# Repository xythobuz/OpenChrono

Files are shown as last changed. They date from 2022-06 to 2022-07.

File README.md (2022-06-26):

# OpenChrono

Chronograph for Airsoft use, released as Free Open Source hardware and software!

Uses a 3D printed housing to hold an Arduino, an OLED display, batteries and two photosensitive IR light barriers.

Fixed mounting on the front of the gun in the style of a silencer.

Can optionally also include UV LEDs to illuminate tracer BBs.

Please also [take a look at the write-up on my website](https://www.xythobuz.de/openchrono.html)!

## Hardware

Use the included OpenSCAD design file in `hardware/openchrono.scad` to render your own custom STLs that fit your use-case.

### Required Parts

Besides some common stuff like soldering wire and hotglue you need the following parts to build this project.

| Description | Type | Count |
| --- | --- | ----- |
| Arduino Nano | | 1x |
| LCD 128x64 I2C | SSD1306 0.96" | 1x |
| Slide Switch | | 1x |
| IR Phototransistor | SFH 309 FA-5  | 2x |
| IR LED 3mm | | 2x |
| Resistor | 1k Ohm | 2x |
| Resistor | 50 Ohm | 1x |
| Screw | M2 10mm | 4x |
| Screw | M2.5 10mm | 2x |
| Screw | M3 16mm | 8x |
| Heatmelt Insert | M3 <= 10mm | 8x |

For the UV tracer option you also need the following parts.

| Description | Type | Count |
| --- | --- | ----- |
| UV LED 3mm  | | 2x |
| Resistor | 50 Ohm  | 1x |

You have different options for powering the project.
My first version for testing uses a pre-made AA battery holder.

| Description | Type | Count |
| --- | --- | ----- |
| AA Battery | | 3x |
| AA Bat. Holder | | 1x |
| Screw (sunk) | M3 <= 6mm | 2x |

The originally intended variant is a AAA battery holder printed into the model.
I don't have the terminals for that yet so it is not finished.

| Description | Type | Count |
| --- | ---- | ----- |
| AAA Battery | | 3x |
| Bat. Terminal Neg. | | 3x |
| Bat. Terminal Pos. | | 3x |

The AA and AAA options are not recommended due to their bulk and weight!
They also have problems with disconnections on firing impulses.

The preferred version uses a single LiPo cell and a charger PCB.

| Description | Type | Count |
| --- | --- | ----- |
| LiPo Battery | 600mAh | 1x |
| Resistor SMD | 4k Ohm | 1x |
| Charging Module | TP4056 | 1x |
| Screw | M3 <= 6mm | 4x |

Be careful though!
If you use the LiPo charger board, they normally come with the charge current set to 1A with a 1.2k Ohm resistor.
You need to put in a higher valued resistor instead, otherwise the small battery will be charged with far too much current and the charger will get very hot.
I recommend 4k Ohm or more.
See [this page for more info](https://www.best-microcontroller-projects.com/tp4056.html#TP4056_Current_Programming_Resistor).

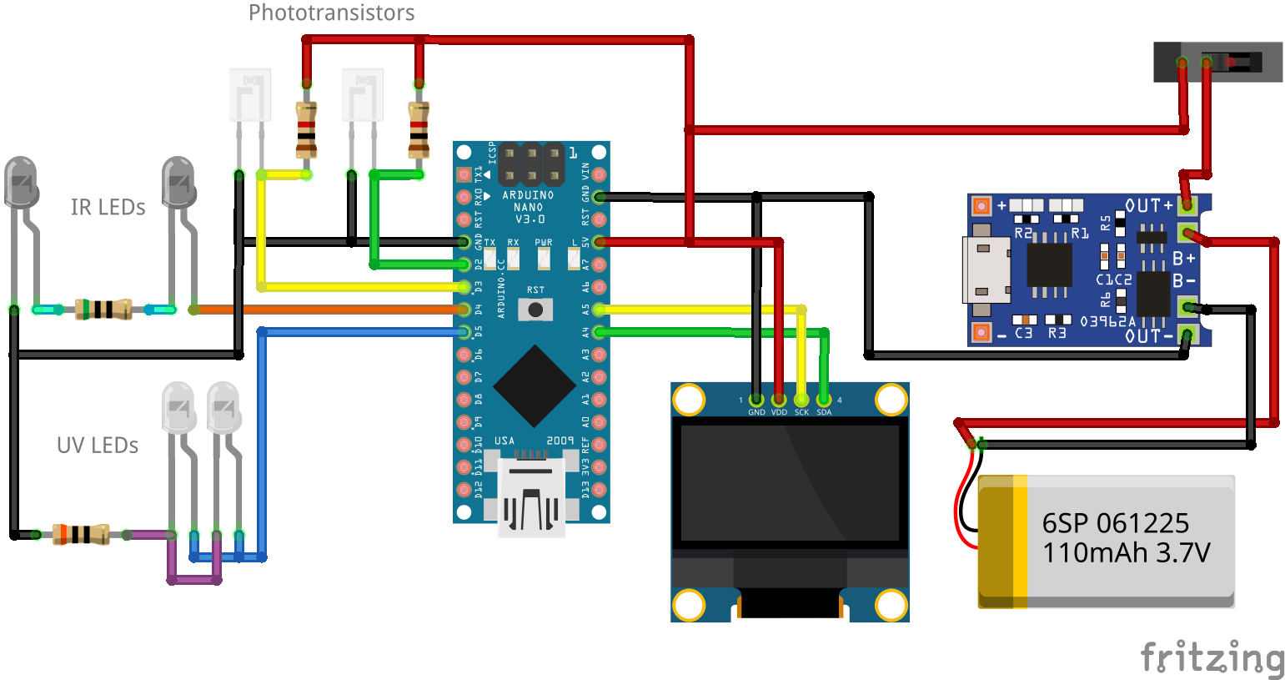
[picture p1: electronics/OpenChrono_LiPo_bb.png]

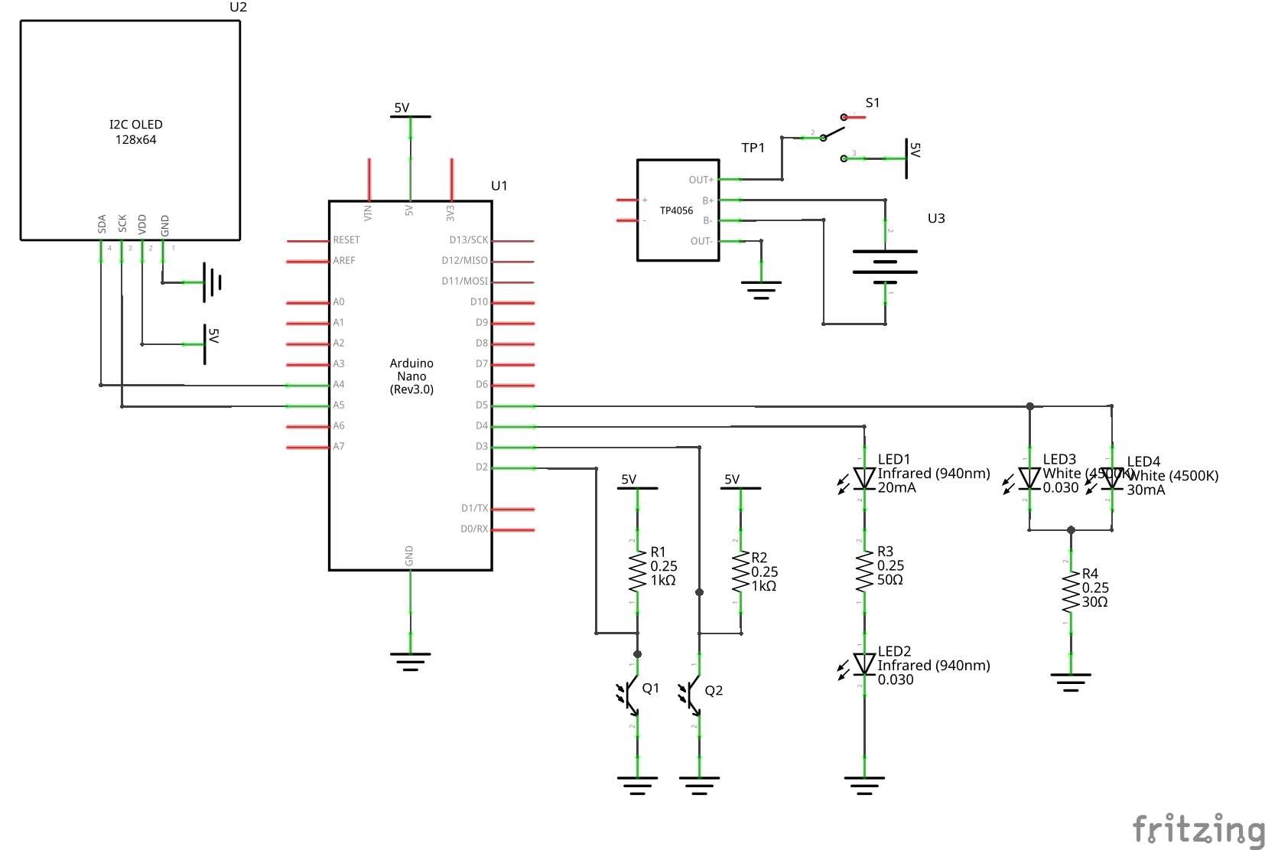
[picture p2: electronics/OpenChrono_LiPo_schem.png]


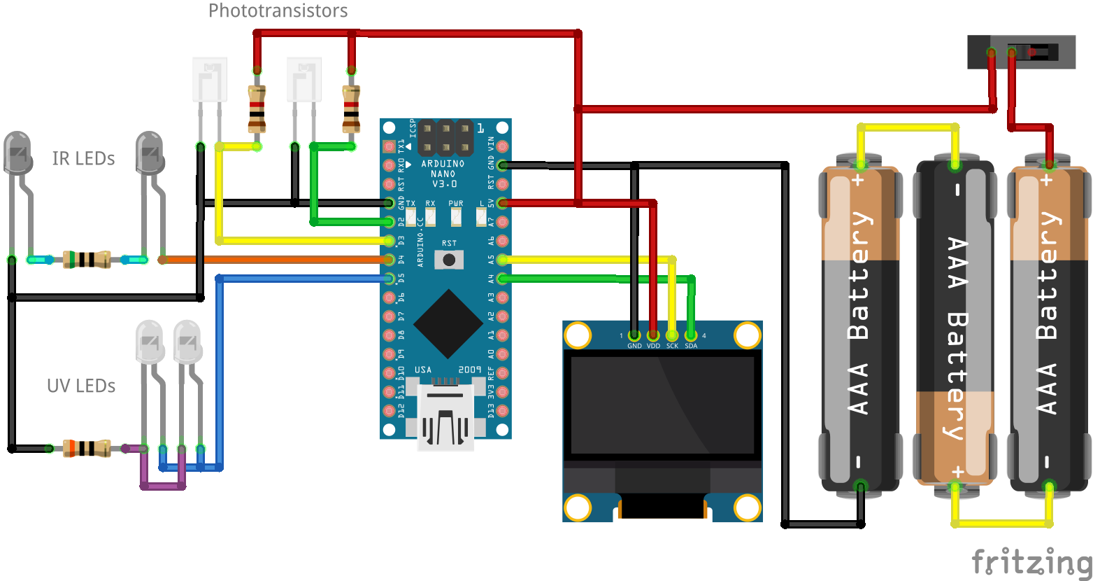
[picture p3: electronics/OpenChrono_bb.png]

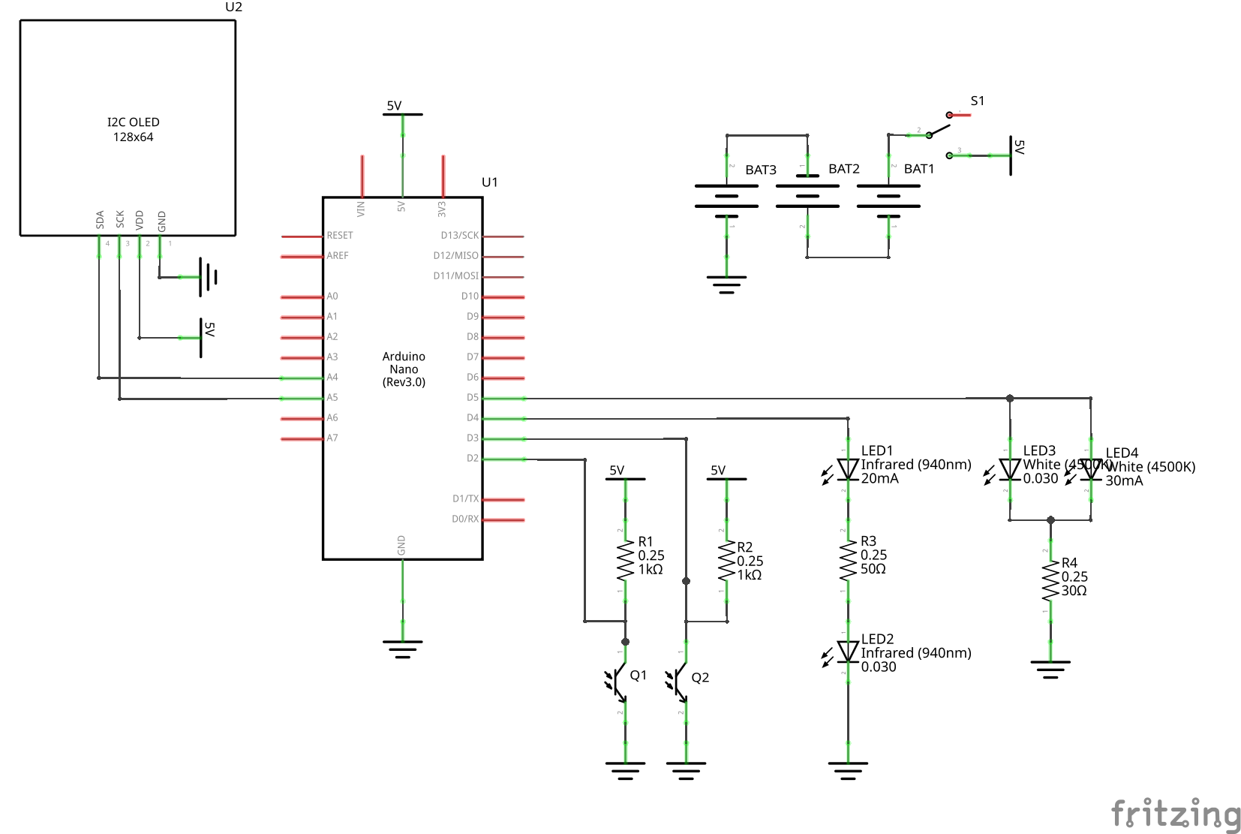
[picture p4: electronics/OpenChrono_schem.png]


### Resistor Values

The proper values for the IR LED current-limiting resistors, as well as the pull-up resistors for the phototransistors depend on the exact parts used.
We want to run the transistor in "switch mode", as [described here](https://www.electronics-notes.com/articles/electronic_components/transistor/phototransistor-circuits-applications.php).
So we need to keep the pull-up value low enough that it quickly is able to pull the IO back to high when the BB passes.
At the same time we also want the LED resistor as low as possible, so the transistor properly switches the IO to low when the light is shining on it.

I built a first prototype with potis instead of resistors on the outside of the case, to be able to adjust the values while measuring the outputs with an oscilloscope.
Using this setup, I arrived at values of 100 Ohm for the LEDs at 4V supply voltage, and 1k Ohm for the phototransistors.
When I later ran again with batteries that had a bit lower voltage, it no longer worked reliably.
So for use with 3x AA(A) batteries, I went down to 50 Ohm for the LEDs.

Also note the type of the phototransistor, "SFH 309 FA-5".
The '5' at the end gives the current that passes when light shines on the sensor, in this case 1.6mA - 3.2mA.
So if you use a different sensor you will probably have to adjust the resistor values!

## Software

This project uses the [U8g2 library by olikraus](https://github.com/olikraus/u8g2) to draw to the I2C OLED display.

You can compile and flash the software using either PlatformIO or the standard Arduino IDE.

With the Arduino IDE [install the U8g2 library using the Library Manager](https://github.com/olikraus/u8g2/wiki/u8g2install) and then flash as usual.

For PlatformIO run something like the following command.

    pio run -t upload --upload-port /dev/ttyUSB0

Replace `/dev/ttyUSB0` with the port you are using.

### Configuration

Take a look at `firmware/OpenChrono/config.h`.
This file contains all the settings you can change as a user.

The most important setting is `SENSOR_DISTANCE`, which is given from the 3D model of the case.
It is echoed when rendering the OpenSCAD design.

You can set `BB_WEIGHT` to the one you use most commonly, and `BB_WEIGHTS` to others interesting for you (`BB_WEIGHTS` should include `BB_WEIGHT`).
These values are used to calculate the energy in Joules.

Set `PREFERRED_UNITS` to what you would like to see in the 2D graph.

The range of speeds that can be measured is determined by `TIMER_PRESCALER`.
Take a look at the comment in `firmware/OpenChrono/ticks.cpp` for details.

## License

OpenChrono is licensed under the [GNU General Public License](https://www.gnu.org/licenses/gpl-3.0.en.html).

    Copyright (c) 2022 Thomas Buck <thomas@xythobuz.de>

    OpenChrono is free software: you can redistribute it and/or modify
    it under the terms of the GNU General Public License as published by
    the Free Software Foundation, either version 3 of the License, or
    (at your option) any later version.

    OpenChrono is distributed in the hope that it will be useful,
    but WITHOUT ANY WARRANTY; without even the implied warranty of
    MERCHANTABILITY or FITNESS FOR A PARTICULAR PURPOSE.  See the
    GNU General Public License for more details.

    You should have received a copy of the GNU General Public License
    along with OpenChrono.  If not, see <https://www.gnu.org/licenses/>.

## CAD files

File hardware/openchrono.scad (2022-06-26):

/*
 * Copyright (c) 2022 Thomas Buck <thomas@xythobuz.de>
 *
 * OpenChrono is free software: you can redistribute it and/or modify
 * it under the terms of the GNU General Public License as published by
 * the Free Software Foundation, either version 3 of the License, or
 * (at your option) any later version.
 *
 * OpenChrono is distributed in the hope that it will be useful,
 * but WITHOUT ANY WARRANTY; without even the implied warranty of
 * MERCHANTABILITY or FITNESS FOR A PARTICULAR PURPOSE.  See the
 * GNU General Public License for more details.
 *
 * You should have received a copy of the GNU General Public License
 * along with OpenChrono.  If not, see <https://www.gnu.org/licenses/>.
 */

outer_dia = 55;
inner_dia = 8.5;
height = 100;

body_gap = 0.1;

body_screw_off = 10;
body_screw_pos = 20;
body_screw_dia = 3.3;
body_screw_head = 6.0;
body_screw_depth = 3.2;
body_screw_insert_dia = 4.8;
body_screw_insert_height = 12.0;

lcd_pcb_w = 29.0;
lcd_pcb_h = 29.0;
lcd_pcb_d = 5.2;
lcd_hole_dia = 1.9;
lcd_hole_w = 6.0;
lcd_hole_h = 2.5;
lcd_off = 10.0;
lcd_hole_off_x = 23.1;
lcd_hole_off_y = 23.65;
lcd_hole_off_y_total = 0.4;
lcd_hole_screw_len = 10.0;

arduino_w = 19.0;
arduino_h = 46.5 + 10;
arduino_d = 10.0;

bat_w = 11.5;
bat_l = 45.5;
bat_tab_w = 9.5;
bat_tab_h = 8.5;
bat_tab_d = 2.5; // TODO?
bat_tab_con_w = 5.0; // TODO?
bat_tab_con_h = 6.5; // TODO?
bat_spring_w = 7.5; // TODO?
bat_spring_dist = 7.5; // TODO?
bat_wall = 1.0;
bat_angle = 48;

led_dia = 3.3;
led_l = 4.5;
led_off = 15;
led_ridge_dia = 4.2;
led_ridge_h = 1.6;

switch_w = 12.0;
switch_h = 6.5;
switch_d = 10.0;
switch_plate_w = 20.5;
switch_plate_h = switch_h;
switch_dia = 2.4;
switch_screw_l = 10.0;
switch_screw_d = 15.0;
switch_off = 15;

// 1911
thread_profile_1911 = [
    true, // type is_male
    12.0, // diameter
    1.0, // pitch
    0.0, // offset
    9.0, // length
    0.0, // offset dia
    9.1, // inner hole
    true, // is cw thread
];

// M14x1.0 CW female thread
thread_profile_m14_cw = [
    false, // type is_male
    14.0, // diameter
    1.0, // pitch
    0.0, // offset
    12.0, // length
    0.0, // offset dia
    8.5, // inner hole
    true, // is cw thread
];

// M14x1.0 CCW female thread
thread_profile_m14_ccw = [
    false, // type is_male
    14.0, // diameter
    1.0, // pitch
    0.0, // offset
    12.0, // length
    0.0, // offset dia
    8.5, // inner hole
    false, // is cw thread
];

// ASG / KWC Cobray Ingram M11 CO2 NBB 6mm
thread_profile_mac11 = [
    false, // type is_male
    16.5, // diameter
    1.5, // pitch
    9.0, // offset
    10.0, // length
    20.0, // offset dia
    8.5, // inner hole
    true, // is cw thread
];

thread_profile_giant = [
    false, // type is_male
    34.0, // diameter
    1.0, // pitch
    0.0, // offset
    10.0, // length
    0.0, // offset dia
    8.5, // inner hole
    true, // is cw thread
];

thread_profiles = [
    thread_profile_1911,
    thread_profile_m14_cw,
    thread_profile_m14_ccw,
    thread_profile_mac11,
    thread_profile_giant
];

thread_base = 5.0;

test_bat_w = 47;
test_bat_h = 59;
test_bat_d = 15;
test_bat_dia = 2.9;
test_bat_off = 30.5;
test_bat_l = 8;

thread_adapter_screw_inset = 5;
thread_adapter_in_body = 5;
thread_adapter_h = body_screw_insert_height - thread_adapter_in_body;

text1 = [
    "OpenChrono",
    "Liberation Sans:style=Bold",
    12.0,
    2.0,
    55
];
text2 = [
    "by xythobuz.de",
    "Liberation Sans:style=Bold",
    9.0,
    2.0,
    -60
];

text3 = [
    "OpenChrono",
    "Liberation Sans:style=Bold",
    12.0 - 4,
    1.0,
    70
];
text4 = [
    "by xythobuz.de",
    "Liberation Sans:style=Bold",
    9.0 - 2,
    1.0,
    -70
];

texts_left = [ text1, text2 ];
texts_lipo = [ text3, text4 ];

lipo_lid_height = 65;
lipo_lid_width = 80;
lipo_lid_d = 3.0;
lipo_lid_gap = 0.5;
lipo_lid_gap_d = 0.2;

lipo_lid_screw_d_small = 2.8;
lipo_lid_screw_d_big = 3.3;
lipo_lid_screw_area = 10;
lipo_lid_screw_len = 10.0;
lipo_lid_screw_off = 5.0;

lipo_lid_compartment_d = 15.0;
lipo_lid_compartment_w = lipo_lid_width - 2 * lipo_lid_screw_area - 5;

lipo_pcb_w = 18.0;
lipo_pcb_h = 29.0;
lipo_pcb_d = 5.0;
lipo_pcb_usb_w = 9.0;
lipo_pcb_usb_h = 3.6;
lipo_pcb_usb_off = 1.4;
lipo_pcb_usb_wall = 1.5;
lipo_pcb_led_dia = 2.0;
lipo_pcb_led_dist = 5.0;
lipo_pcb_led_off_x = 1.75;
lipo_pcb_led_off_z = 7.0;

lipo_w = 30.0;
lipo_h = 43.0;
lipo_d = 9.0;

enable_gap_support = true;
include_uv_leds = true;

lipo_lid_angle = circum_angle(lipo_lid_width - lipo_lid_gap * 2, outer_dia);
lipo_lid_angle_hole = circum_angle(lipo_lid_width, outer_dia);
lipo_lid_angle_compartment = circum_angle(lipo_lid_compartment_w, outer_dia);

bat_h = bat_l + bat_spring_dist + 2 * bat_wall + 2 * bat_tab_d;

$fn = 42;

echo("sensor_distance", height - 2 * led_off);

if (include_uv_leds)
echo("uv_led_distance", led_off / 2);

// https://dkprojects.net/openscad-threads/
include <extern/threads.scad>

// how deep things on the outside have to be set in
function circle_offset_deviation(off, dia) =
    dia * (1 - sin(acos(off * 2 / dia))) / 2;

// circumference to angle
function circum_angle(width, dia) = width / dia * 180 / 3.141;

// from https://3dprinting.stackexchange.com/questions/10638/creating-pie-slice-in-openscad
module pie_slice(r, a) {
    intersection() {
        circle(r = r);
        
        square(r);
        
        rotate(a - 90)
        square(r);
    }
}

module lcd_cutout() {
    difference() {
        cube([lcd_pcb_w, lcd_pcb_h, lcd_pcb_d + 10]);
        
        for (x = [0, lcd_pcb_w - lcd_hole_w])
        for (y = [0, lcd_pcb_h - lcd_hole_w])
        translate([x, y, -1])
        cube([lcd_hole_w, lcd_hole_w, lcd_hole_h + 1]);
        
        // TODO hacky
        if (enable_gap_support)
        translate([0, (lcd_pcb_w - 1) / 2, 1])
        cube([lcd_pcb_w, 1, 8]);
    }
            
    for (x = [0, lcd_hole_off_x])
    for (y = [0, lcd_hole_off_y])
    translate([x + lcd_hole_w / 2, y + lcd_hole_w / 2 - lcd_hole_off_y_total, lcd_hole_h - lcd_hole_screw_len])
    cylinder(d = lcd_hole_dia, h = lcd_hole_screw_len + 1);
}

module arduino_cutout() {
    cube([arduino_w, arduino_h, arduino_d]);
}

module bat_cutout() {
    // battery
    translate([0, 0, bat_tab_d + bat_wall])
    cube([bat_w, bat_w, bat_l + bat_spring_dist]);
    
    // negative terminal
    for (z = [0, bat_l + bat_spring_dist + 2 * bat_wall + bat_tab_d])
    translate([(bat_w - bat_tab_w) / 2, (bat_w - bat_tab_h) / 2, z])
    cube([bat_tab_w, bat_tab_h + (bat_w - bat_tab_h) / 2, bat_tab_d]);

    // spring
    for (z = [bat_tab_d, bat_l + bat_spring_dist + bat_wall + bat_tab_d])
    translate([(bat_w - bat_spring_w) / 2, (bat_w - bat_spring_w) / 2, z - 0.1])
    cube([bat_spring_w, bat_spring_w + (bat_w - bat_spring_w) / 2, bat_wall + 0.2]);
}

module switch_cutout() {
    translate([-switch_w / 2, -10, -switch_h / 2])
    cube([switch_w, switch_d + 10, switch_h]);
    
    translate([-switch_plate_w / 2, -switch_d, -switch_plate_h / 2])
    cube([switch_plate_w, 10, switch_plate_h]);
    
    for (x = [1, -1])
    scale([x, 1, 1])
    translate([-switch_screw_d / 2, -10, 0])
    rotate([-90, 0, 0])
    cylinder(d = switch_dia, h = switch_screw_l + 10);
}

module thread(profile, thread_draw) {
    if (profile[0]) {
        // male thread
        difference() {
            union() {
                cylinder(d = outer_dia, h = thread_base + body_screw_depth);
                
                scale([1, profile[7] ? 1 : -1, 1])
                metric_thread(profile[1], profile[2], profile[4] + thread_base + body_screw_depth, test=!thread_draw);
            }
            
            translate([0, 0, -1])
            cylinder(d = profile[6], h = profile[4] + thread_base + body_screw_depth + 2);
        }
    } else {
        // female thread
        difference() {
            cylinder(d = outer_dia, h = thread_base + body_screw_depth + profile[4] + profile[3]);
            
            translate([0, 0, -1])
            scale([1, profile[7] ? 1 : -1, 1])
            metric_thread(profile[1], profile[2], profile[4] + thread_base + body_screw_depth + 2, true, test=!thread_draw);
            
            translate([0, 0, thread_base + body_screw_depth + profile[4]])
            cylinder(d = profile[5], h = profile[3] + 1);
            
            translate([0, 0, -1])
            cylinder(d = profile[6], h = profile[4] + thread_base + profile[3] + 2);
        } 
    }
}

module thread_profile_adapter(profile, draw_profile) {
    difference() {
        thread(profile, draw_profile);
        
        for (r = [45, -45])
        for (r2 = [0, 180])
        rotate([0, 0, r + r2])
        translate([0, (outer_dia - body_screw_insert_dia) / 2 - thread_adapter_screw_inset, 0]) {
            translate([0, 0, -1])
            cylinder(d = body_screw_dia, h = 50);
            
            translate([0, 0, thread_base])
            cylinder(d = body_screw_head, h = 50);
        }
    }
}
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

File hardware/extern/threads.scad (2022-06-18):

/*
 * ISO-standard metric threads, following this specification:
 *          http://en.wikipedia.org/wiki/ISO_metric_screw_thread
 *
 * Copyright 2020 Dan Kirshner - dan_kirshner@yahoo.com
 * This program is free software: you can redistribute it and/or modify
 * it under the terms of the GNU General Public License as published by
 * the Free Software Foundation, either version 3 of the License, or
 * (at your option) any later version.
 *
 * This program is distributed in the hope that it will be useful,
 * but WITHOUT ANY WARRANTY; without even the implied warranty of
 * MERCHANTABILITY or FITNESS FOR A PARTICULAR PURPOSE.  See the
 * GNU General Public License for more details.
 *
 * See <http://www.gnu.org/licenses/>.
 *
 * Version 2.4.  2019-07-14  Add test option - do not render threads.
 * Version 2.3.  2017-08-31  Default for leadin: 0 (best for internal threads).
 * Version 2.2.  2017-01-01  Correction for angle; leadfac option.  (Thanks to
 *                           Andrew Allen <a2intl@gmail.com>.)
 * Version 2.1.  2016-12-04  Chamfer bottom end (low-z); leadin option.
 * Version 2.0.  2016-11-05  Backwards compatibility (earlier OpenSCAD) fixes.
 * Version 1.9.  2016-07-03  Option: tapered.
 * Version 1.8.  2016-01-08  Option: (non-standard) angle.
 * Version 1.7.  2015-11-28  Larger x-increment - for small-diameters.
 * Version 1.6.  2015-09-01  Options: square threads, rectangular threads.
 * Version 1.5.  2015-06-12  Options: thread_size, groove.
 * Version 1.4.  2014-10-17  Use "faces" instead of "triangles" for polyhedron
 * Version 1.3.  2013-12-01  Correct loop over turns -- don't have early cut-off
 * Version 1.2.  2012-09-09  Use discrete polyhedra rather than linear_extrude ()
 * Version 1.1.  2012-09-07  Corrected to right-hand threads!
 */

// Examples.
//
// Standard M8 x 1.
// metric_thread (diameter=8, pitch=1, length=4);

// Square thread.
// metric_thread (diameter=8, pitch=1, length=4, square=true);

// Non-standard: long pitch, same thread size.
//metric_thread (diameter=8, pitch=4, length=4, thread_size=1, groove=true);

// Non-standard: 20 mm diameter, long pitch, square "trough" width 3 mm,
// depth 1 mm.
//metric_thread (diameter=20, pitch=8, length=16, square=true, thread_size=6,
//               groove=true, rectangle=0.333);

// English: 1/4 x 20.
//english_thread (diameter=1/4, threads_per_inch=20, length=1);

// Tapered.  Example -- pipe size 3/4" -- per:
// http://www.engineeringtoolbox.com/npt-national-pipe-taper-threads-d_750.html
// english_thread (diameter=1.05, threads_per_inch=14, length=3/4, taper=1/16);

// Thread for mounting on Rohloff hub.
//difference () {
//   cylinder (r=20, h=10, $fn=100);
//
//   metric_thread (diameter=34, pitch=1, length=10, internal=true, n_starts=6);
//}


// ----------------------------------------------------------------------------
function segments (diameter) = min (50, max (ceil (diameter*6), 25));


// ----------------------------------------------------------------------------
// diameter -    outside diameter of threads in mm. Default: 8.
// pitch    -    thread axial "travel" per turn in mm.  Default: 1.
// length   -    overall axial length of thread in mm.  Default: 1.
// internal -    true = clearances for internal thread (e.g., a nut).
//               false = clearances for external thread (e.g., a bolt).
//               (Internal threads should be "cut out" from a solid using
//               difference ()).  Default: false.
// n_starts -    Number of thread starts (e.g., DNA, a "double helix," has
//               n_starts=2).  See wikipedia Screw_thread.  Default: 1.
// thread_size - (non-standard) axial width of a single thread "V" - independent
//               of pitch.  Default: same as pitch.
// groove      - (non-standard) true = subtract inverted "V" from cylinder
//                (rather thanadd protruding "V" to cylinder).  Default: false.
// square      - true = square threads (per
//               https://en.wikipedia.org/wiki/Square_thread_form).  Default:
//               false.
// rectangle   - (non-standard) "Rectangular" thread - ratio depth/(axial) width
//               Default: 0 (standard "v" thread).
// angle       - (non-standard) angle (deg) of thread side from perpendicular to
//               axis (default = standard = 30 degrees).
// taper       - diameter change per length (National Pipe Thread/ANSI B1.20.1
//               is 1" diameter per 16" length). Taper decreases from 'diameter'
//               as z increases.  Default: 0 (no taper).
// leadin      - 0 (default): no chamfer; 1: chamfer (45 degree) at max-z end;
//               2: chamfer at both ends, 3: chamfer at z=0 end.
// leadfac     - scale of leadin chamfer (default: 1.0 = 1/2 thread).
// test        - true = do not render threads (just draw "blank" cylinder).
//               Default: false (draw threads).
module metric_thread (diameter=8, pitch=1, length=1, internal=false, n_starts=1,
                      thread_size=-1, groove=false, square=false, rectangle=0,
                      angle=30, taper=0, leadin=0, leadfac=1.0, test=false)
{
   // thread_size: size of thread "V" different than travel per turn (pitch).
   // Default: same as pitch.
   local_thread_size = thread_size == -1 ? pitch : thread_size;
   local_rectangle = rectangle ? rectangle : 1;

   n_segments = segments (diameter);
   h = (test && ! internal) ? 0 : (square || rectangle) ? local_thread_size*local_rectangle/2 : local_thread_size / (2 * tan(angle));

   h_fac1 = (square || rectangle) ? 0.90 : 0.625;

   // External thread includes additional relief.
   h_fac2 = (square || rectangle) ? 0.95 : 5.3/8;

   tapered_diameter = diameter - length*taper;

   difference () {
      union () {
         if (! groove) {
            if (! test) {
               metric_thread_turns (diameter, pitch, length, internal, n_starts,
                                    local_thread_size, groove, square, rectangle, angle,
                                    taper);
            }
         }

         difference () {

            // Solid center, including Dmin truncation.
            if (groove) {
               cylinder (r1=diameter/2, r2=tapered_diameter/2,
                         h=length, $fn=n_segments);
            } else if (internal) {
               cylinder (r1=diameter/2 - h*h_fac1, r2=tapered_diameter/2 - h*h_fac1,
                         h=length, $fn=n_segments);
            } else {

               // External thread.
               cylinder (r1=diameter/2 - h*h_fac2, r2=tapered_diameter/2 - h*h_fac2,
                         h=length, $fn=n_segments);
            }

            if (groove) {
               if (! test) {
                  metric_thread_turns (diameter, pitch, length, internal, n_starts,
                                       local_thread_size, groove, square, rectangle,
                                       angle, taper);
               }
            }
         }
      }

      // chamfer z=0 end if leadin is 2 or 3
      if (leadin == 2 || leadin == 3) {
         difference () {
            cylinder (r=diameter/2 + 1, h=h*h_fac1*leadfac, $fn=n_segments);

            cylinder (r2=diameter/2, r1=diameter/2 - h*h_fac1*leadfac, h=h*h_fac1*leadfac,
                      $fn=n_segments);
         }
      }

      // chamfer z-max end if leadin is 1 or 2.
      if (leadin == 1 || leadin == 2) {
         translate ([0, 0, length + 0.05 - h*h_fac1*leadfac]) {
            difference () {
               cylinder (r=diameter/2 + 1, h=h*h_fac1*leadfac, $fn=n_segments);
               cylinder (r1=tapered_diameter/2, r2=tapered_diameter/2 - h*h_fac1*leadfac, h=h*h_fac1*leadfac,
                         $fn=n_segments);
            }
         }
      }
   }
}


// ----------------------------------------------------------------------------
// Input units in inches.
// Note: units of measure in drawing are mm!
module english_thread (diameter=0.25, threads_per_inch=20, length=1,
                      internal=false, n_starts=1, thread_size=-1, groove=false,
                      square=false, rectangle=0, angle=30, taper=0, leadin=0,
                      leadfac=1.0, test=false)
{
   // Convert to mm.
   mm_diameter = diameter*25.4;
   mm_pitch = (1.0/threads_per_inch)*25.4;
   mm_length = length*25.4;

   echo (str ("mm_diameter: ", mm_diameter));
   echo (str ("mm_pitch: ", mm_pitch));
   echo (str ("mm_length: ", mm_length));
   metric_thread (mm_diameter, mm_pitch, mm_length, internal, n_starts,
                  thread_size, groove, square, rectangle, angle, taper, leadin,
                  leadfac, test);
}

// ----------------------------------------------------------------------------
module metric_thread_turns (diameter, pitch, length, internal, n_starts,
                            thread_size, groove, square, rectangle, angle,
                            taper)
{
   // Number of turns needed.
   n_turns = floor (length/pitch);

   intersection () {
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

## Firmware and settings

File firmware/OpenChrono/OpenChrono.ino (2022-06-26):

/*
 * OpenChrono.ino
 *
 * OpenChrono BB speed measurement device.
 *
 * Copyright (c) 2022 Thomas Buck <thomas@xythobuz.de>
 *
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
 * The goal is to measure the speed of a BB moving through the device.
 */

#include "timing.h"
#include "ticks.h"
#include "lcd.h"
#include "config.h"

static void calculate(uint16_t a, uint16_t b) {
    uint16_t ticks = 0;

    if (b >= a) {
        // simple case - just return difference
        ticks = b - a;
    } else {
        // the timer overflowed between measurements!
        int32_t tmp = ((int32_t)b) - ((int32_t)a);
        tmp += 0x10000;
        ticks = (uint16_t)tmp;
    }

    double speed = tick_to_metric(ticks);
    if ((speed >= MIN_SPEED) && (speed <= MAX_SPEED)) {
        // only register realistic velocities
        tick_new_value(ticks);
        lcd_new_value();
    }
}

static void measure() {
    cli(); // disable interrupts before interacting with values

    // reset interrupts
    trigger_a = 0;
    trigger_b = 0;

    uint16_t a = time_a, b = time_b;

    sei(); // enable interrupts immediately afterwards

    calculate(a, b);
}

void setup() {
    // we simply turn on the IR LEDs all the time
    pinMode(IR_LED_PIN, OUTPUT);
    digitalWrite(IR_LED_PIN, HIGH);

    // but the UV LEDs will only be pulsed on firing!
    pinMode(UV_LED_PIN, OUTPUT);
    digitalWrite(UV_LED_PIN, LOW);

    lcd_init();
    delay(SCREEN_TIMEOUT); // show splash screen

    timer_init();
    interrupt_init();
}

void loop() {
    if (trigger_b) {
        if (trigger_a) {
            // we got an event on both inputs
            measure();
        } else {
            // we got a false second trigger!
            // clear so next calculation will be correct
            trigger_b = 0;
        }
    }

    lcd_loop();
}

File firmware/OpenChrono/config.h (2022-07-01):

/*
 * config.h
 *
 * OpenChrono BB speed measurement device.
 *
 * Copyright (c) 2022 Thomas Buck <thomas@xythobuz.de>
 *
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
 * You should have received a copy of the GNU General Public License
 * along with OpenChrono.  If not, see <https://www.gnu.org/licenses/>.
 */

#ifndef __CONFIG_H__
#define __CONFIG_H__

// --------------------------------------

#define VERSION "0.0.1"

// --------------------------------------

#define SENSOR_DISTANCE 70.0 /* in mm */

#define BB_WEIGHT 0.25 /* in g */
#define BB_WEIGHTS { 0.20, 0.23, 0.25, 0.28, 0.475 } /* in g */

// --------------------------------------

// which unit to show on history screen

#define METRIC 0
#define IMPERIAL 1
#define JOULES 2

#define PREFERRED_UNITS METRIC

// --------------------------------------

// order and duration of screens

#define SCREEN_CURRENT 0
#define SCREEN_MIN 1
#define SCREEN_AVERAGE 2
#define SCREEN_MAX 3
#define SCREEN_HISTORY 4

#define SCREEN_ROTATION { \
    SCREEN_CURRENT,       \
    SCREEN_CURRENT,       \
    SCREEN_MIN,           \
    SCREEN_AVERAGE,       \
    SCREEN_MAX,           \
    SCREEN_HISTORY,       \
    SCREEN_HISTORY        \
}

#define SCREEN_TIMEOUT 2500 /* in ms */
#define FLIP_SCREEN 0

// --------------------------------------

// lcd config

#define LCD_TYPE U8G2_SSD1306_128X64_NONAME_F_HW_I2C

#define HEADING_FONT u8g2_font_VCR_OSD_tr
#define TEXT_FONT u8g2_font_NokiaLargeBold_tr
#define SMALL_FONT u8g2_font_helvB08_tr

// --------------------------------------

// history for graph of speeds.
// should not be too big!

#define HISTORY_BUFFER 50

// --------------------------------------

#define IR_LED_PIN 4
#define UV_LED_PIN 5

// --------------------------------------

// with a prescaler of 1, we can measure from 17m/s to 1120000m/s
// with a prescaler of 8, we can measure from 2.14m/s to 140000m/s
// with a prescaler of 64, we can measure from 0.27m/s to 17500m/s
// see comment in ticks.cpp

// allowed values: 1, 8, 64, 256, 1024
#define TIMER_PRESCALER 64

// values outside this range will be ignored
#define MIN_SPEED 0.3 /* in m/s */
#define MAX_SPEED 2000.0 /* in m/s */

// enable to keep UV LED on 100x as long
//#define DEBUG_LONG_UV_TIME

// --------------------------------------

// placeholder data for debugging purposes

#define DEBUG_TICK_COUNT 0
#define DEBUG_TICK_DATA {}

//#define DEBUG_TICK_COUNT 8
//#define DEBUG_TICK_DATA { 8000, 10000, 9000, 11000, 8500, 9500, 10000, 7000 }

// --------------------------------------

#endif // __CONFIG_H__

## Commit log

2022-06-19 turn on IR LEDs with GPIO
2022-06-20 various firmware changes. fix measurement. add uv led support. small values with decimal places. fix graph. set prescaler.
    [OpenChrono.ino, config.h]
2022-06-20 3d model changes. add uv led. thread adapter as separate part. added text. small fixes.
    [openchrono.scad]
2022-06-20 Add Fritzing schematics
    [OpenChrono.fzz]
2022-06-25 bunch of changes to 3d model. firmware now has min and max speed setting.
    [openchrono.scad]
2022-06-26 add gpl license
    [openchrono.scad]
2022-06-26 add lipo fritzing schematics
    [OpenChrono_LiPo.fzz]
2022-07-01 uv leds in series in schematics
    [OpenChrono.fzz, OpenChrono_LiPo.fzz]
2022-07-01 add debug mode that keeps uv leds on longer.
